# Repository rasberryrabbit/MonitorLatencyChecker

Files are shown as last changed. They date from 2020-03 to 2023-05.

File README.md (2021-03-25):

# MonitorLatencyChecker
Simple Monitor Latency checker with Arduino Pro Micro 5V 16MHz.

App is WIP.

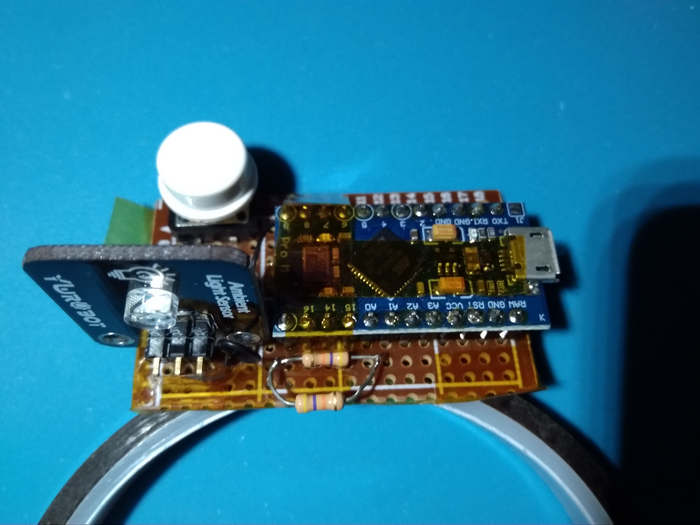
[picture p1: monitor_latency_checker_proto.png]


Button on circuit do mouse clicking emulation. Mouse pointer must inside app's black or white window.

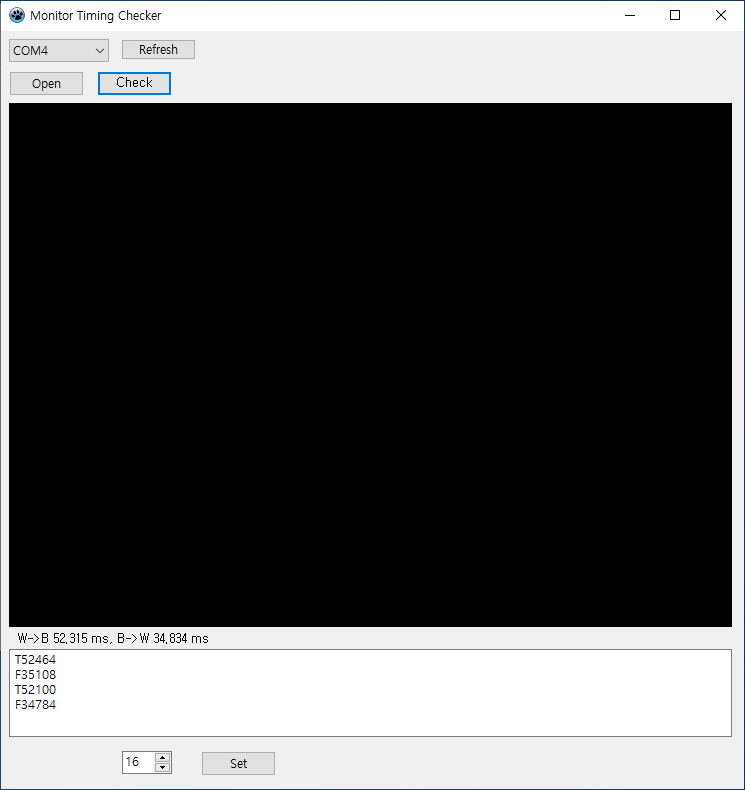
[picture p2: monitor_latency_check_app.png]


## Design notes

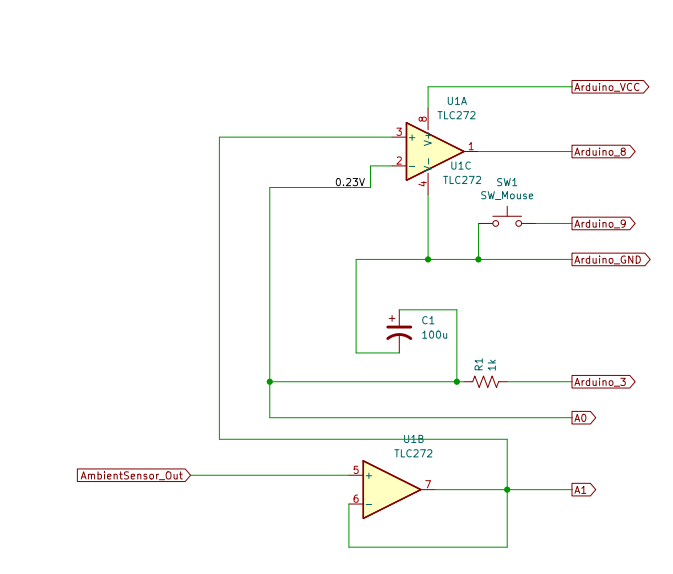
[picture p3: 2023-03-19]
Monitor_latency_checker_circuit.png

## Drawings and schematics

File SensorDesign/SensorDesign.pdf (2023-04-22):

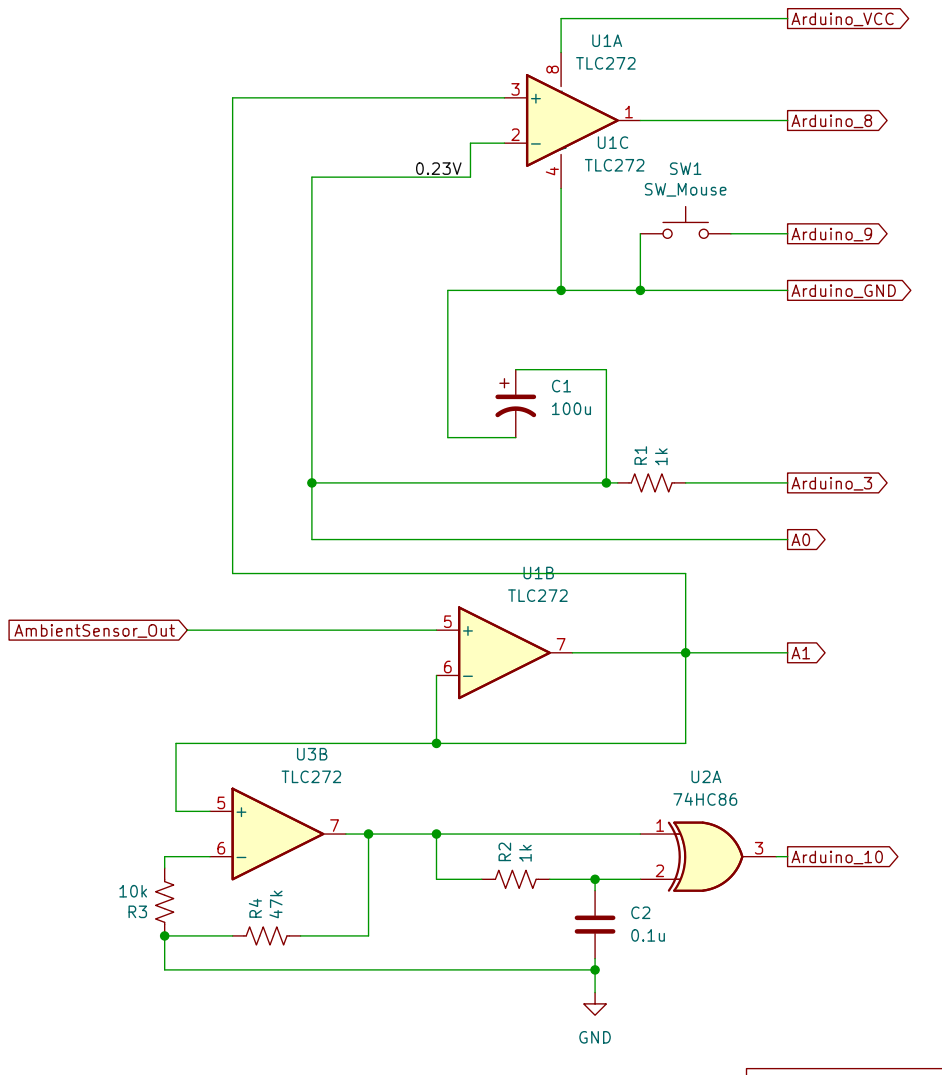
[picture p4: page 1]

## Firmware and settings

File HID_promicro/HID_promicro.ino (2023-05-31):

#include <HID-Project.h>
#include <HID-Settings.h>
#include <PinChangeInterrupt.h>

/* 
 *  firmware for arduino pro micro
 *  16MHz 5V board.
 *  pin 8 = photodiode input.
 *  pin 9 = toggle trigger
 *  pin 10 = Edge trigger
 */

#define PIN_MOUSE 9
#define PIN_PHOTO 8
#define PIN_EDGE 10
#define PIN_PWM 3
#define PWM_DEF 12

#define USE_RAW_TIME
#define USE_EDGE
#define USE_MOUSE_INT

const int PIN_LED = LED_BUILTIN; //
uint8_t rawData[64];
uint8_t obuf[32];

char flag='F';
int result=0;
unsigned long st,et;
unsigned long re;
int old=LOW;
int tr_enable=0;
unsigned long mouse_st, mouse_et;
unsigned long *rp;
int sendsize=16;
int i, pwm0, pwm1;

#ifdef USE_MOUSE_INT
void PinIntMouse(void) {
  tr_enable=1;
}
#endif

#ifndef USE_EDGE
void PinIntPhoto(void) {
  if(!result) {
    st=et;
    et=micros();
    if(digitalRead(PIN_PHOTO)==HIGH)
      flag='T';
      else flag='F';
    result=1;
  }
}
#else
void PinIntEDGE(void) {
  // falling edge
  if(result==0)
    st=et;
  et=micros();
  result=1;
}
#endif

void setup() {
  pinMode(PIN_PHOTO, INPUT);
  pinMode(PIN_EDGE, INPUT);
  pinMode(PIN_MOUSE, INPUT_PULLUP);
  pinMode(PIN_PWM, OUTPUT);
  pinMode(PIN_LED, OUTPUT);
  
  Serial.begin(115200);
  Mouse.begin();
  tr_enable=0;
  result=0;
  rp=(unsigned long *)&obuf[1];
  et=micros();
  mouse_st=millis();
  // Pin 3, 976Hz
  TCCR3A = _BV(COM3B1) | _BV(WGM31) | _BV(WGM30);
  TCCR3B = _BV(CS32);
  analogWrite(PIN_PWM,PWM_DEF); // 0.233mV
#ifndef USE_EDGE
  attachPCINT(digitalPinToPCINT(PIN_PHOTO), PinIntPhoto, CHANGE);
#else  
  attachPCINT(digitalPinToPCINT(PIN_EDGE), PinIntEDGE, CHANGE);
#endif

#ifdef USE_MOUSE_INT
  attachPCINT(digitalPinToPCINT(PIN_MOUSE), PinIntMouse, RISING);
#endif
}

void loop() {
  // wait changes and send
  if(result) {
    cli();
    re=et-st;
    obuf[0]=flag;
#ifdef USE_RAW_TIME
    *rp=re;
#else
    snprintf(&obuf[1],16,"%012ld",re);
#endif
    result=0;
    sei();
    // serial print
    Serial.write(obuf,sendsize);
  } else {
    // respond serial
    if(Serial.available()) {
      // set send packet size
      if(Serial.readBytes(rawData,3)==3) {
        if(rawData[0]=='P'&&rawData[1]=='S') {
          sendsize=rawData[2];
          if(sendsize>32)
            sendsize=32;
            else if(sendsize<8)
              sendsize=8;
        } else if(rawData[0]=='C'&&rawData[1]=='A') {
          cli();
          pwm1=analogRead(A1);
          for(i=0;i<50;i++) {
            analogWrite(PIN_PWM,i);
            delay(100);
            pwm0=analogRead(A0);
            if(pwm0>pwm1) {
              i-=2;
              i/=2;
              break;
            }
          }
          if(i<0) i=PWM_DEF;
          analogWrite(PIN_PWM,i);
          sei();
#ifdef USE_RAW_TIME
          *rp=i;
#else
          snprintf(&obuf[1],16,"%2d",i);
#endif
          obuf[0]=(char)0x43;
          Serial.write(obuf,sendsize);
        }
      }
      while(Serial.available()) {
        Serial.read();
      }
      obuf[0]=(char)0x4F;
#ifdef USE_RAW_TIME
      *rp=sendsize;
#else
      snprintf(&obuf[1],16,"%2d",sendsize);
#endif
      Serial.write(obuf,sendsize);
    }
#ifndef USE_MOUSE_INT
    if(digitalRead(PIN_MOUSE)==LOW) {
#else
    if(tr_enable) {
#endif
      mouse_et=millis();
      if(mouse_et-mouse_st>=300) {
        Mouse.click();
        et=micros();
        mouse_st=mouse_et;
      }
#ifdef USE_MOUSE_INT
      tr_enable=0;
#endif
    }
  }
}

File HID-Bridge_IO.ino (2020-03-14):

/*
 Serial Monitor latency checker HID IO
 Pin 2 = Photo Diode
 Pin 4 = Indicator LED
 Board: HoodLoader2 UNO
*/

int flag=0;
int PinRead=2;
int PinWrite=4;
char buf[5];

void setup() {
  // Serial Baud for USB <-> IO
  Serial.begin(2000000);
  // Pin setup
  pinMode(PinRead, INPUT);
  pinMode(PinWrite, OUTPUT);
  digitalWrite(PinWrite, LOW);
}

void loop() {
  // start signal from USB
  if(Serial.available()) {
    if((Serial.readBytes(buf,4)==4) && (memcmp(buf,"IOBG",4)==0)) {
      while(Serial.available()) {
        Serial.read();
      }
      flag=1;
      digitalWrite(PinWrite, LOW);
    }
  }
  // check photo diode and send signal to USB
  if(flag) {
    if(digitalRead(PinRead)==1) {
      Serial.write("IOED");
      flag=0;
      digitalWrite(PinWrite, HIGH);
    }
  }
}

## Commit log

2020-03-15 stable internal UART baudrate.
2020-03-15 use threading.
2020-04-09 Using Arduino pro micro board for fast response.
2020-04-10 Test photodiode sensor.
2020-06-05 Add sensor circuit.
2021-03-25 Update Schematics.
    [SensorDesign.kicad_pcb, SensorDesign.sch]
2021-03-25 Update schemetics.
    [SensorDesign.sch]
2021-03-25 Add prototype image.
2021-03-26 Change Reference voltage to 0.49V
    [SensorDesign.sch]
2021-03-26 Update reference voltage to 0.5V
    [SensorDesign.sch]
2021-03-26 Add circuit image.
2023-03-18 Update circuit.
    [SensorDesign.kicad_sch]
2023-03-19 High PWM Frequency
2023-04-22 Add Edge trigger mode.
    [SensorDesign.kicad_sch]
